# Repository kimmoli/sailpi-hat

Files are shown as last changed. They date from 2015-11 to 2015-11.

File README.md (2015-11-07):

sailpi-hat
==========

Sensors:

  - ADXL345 acceleration sensor (i2c 0x53)
  - BMP180 pressure sensor (i2c 0x77)
  - MCP9800 temperature sensor (i2c 0x4d)
  - MCP3021 AD converter (i2c 0x48)

Connectors:

X2
--

  - 1 +5V output
  - 2 +5V output
  - 3 GND
  - 4 GND
  - 5 shutdown input (connect to GND to shutdown)
  - 6 +12V input
  - 7 +12V input
  - 8 GND
  
X3
--

  - 1 optional analog input (R4B)
  - 2 GND
  - 3 Not connected
  - 4 SCL1
  - 5 SDA1
  - 6 Not connected
  - 7 +3.3V output
  - 8 GND

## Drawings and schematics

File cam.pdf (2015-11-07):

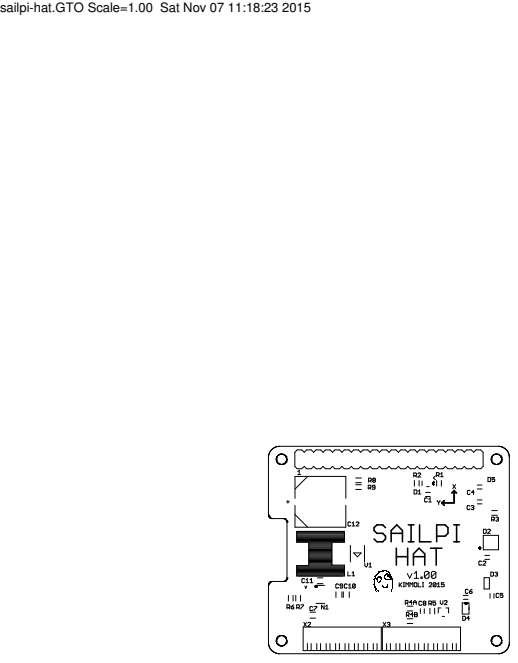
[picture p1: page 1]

sailpi-hat.GTO Scale=1.00 Sat Nov 07 11:18:23 2015

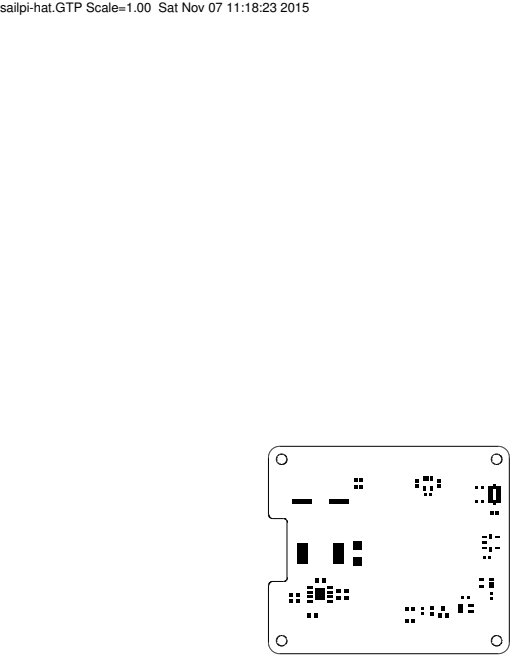
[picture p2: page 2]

sailpi-hat.GTP Scale=1.00 Sat Nov 07 11:18:23 2015

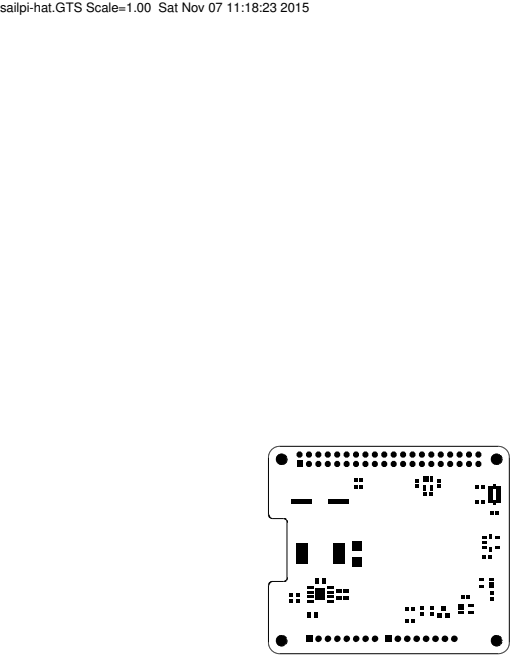
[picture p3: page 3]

sailpi-hat.GTS Scale=1.00 Sat Nov 07 11:18:23 2015

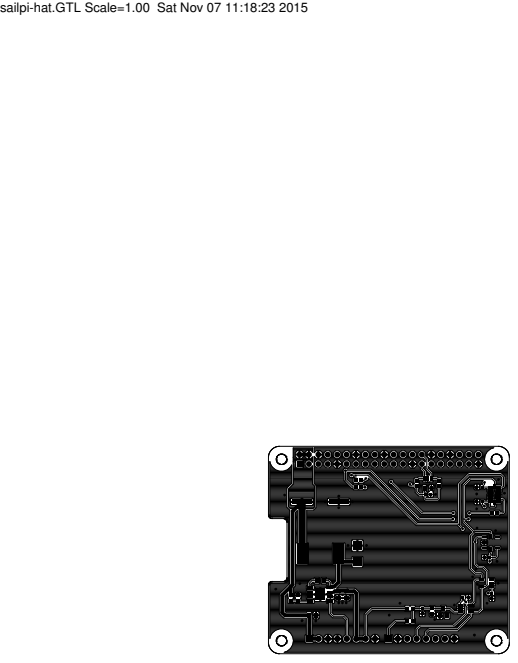
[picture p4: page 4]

sailpi-hat.GTL Scale=1.00 Sat Nov 07 11:18:23 2015

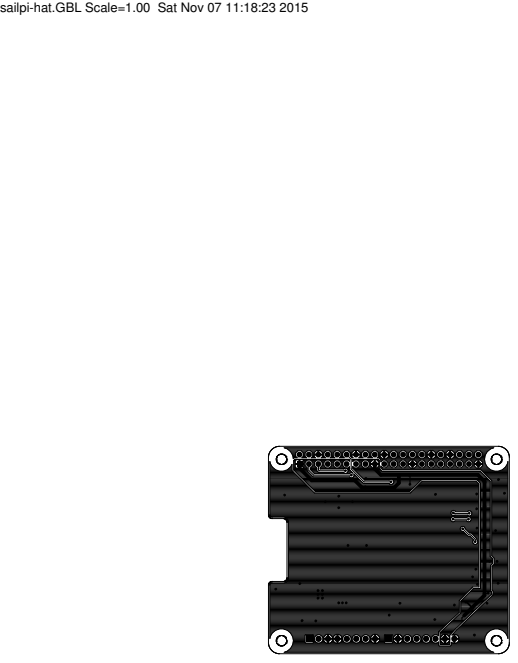
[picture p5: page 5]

sailpi-hat.GBL Scale=1.00 Sat Nov 07 11:18:23 2015

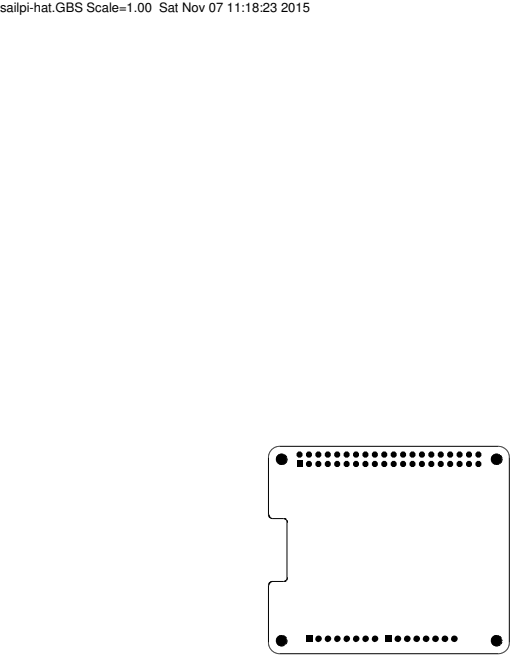
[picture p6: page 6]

sailpi-hat.GBS Scale=1.00 Sat Nov 07 11:18:23 2015

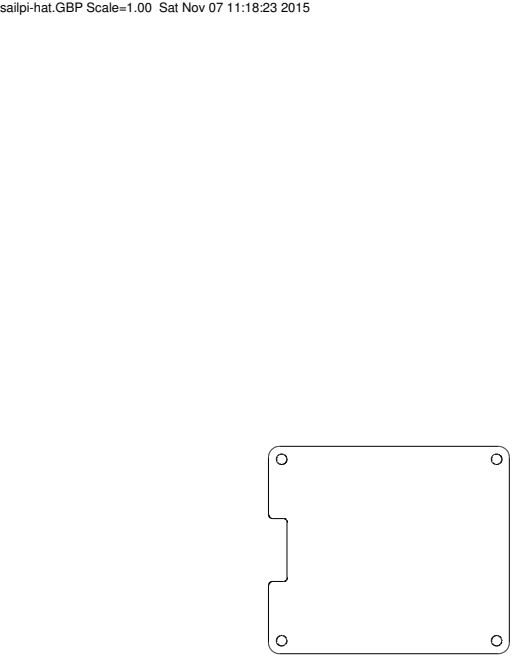
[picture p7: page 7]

sailpi-hat.GBP Scale=1.00 Sat Nov 07 11:18:23 2015

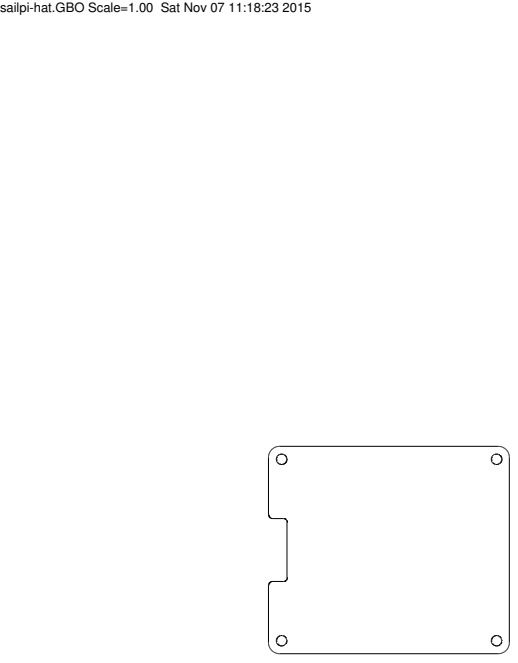
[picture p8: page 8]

sailpi-hat.GBO Scale=1.00 Sat Nov 07 11:18:23 2015

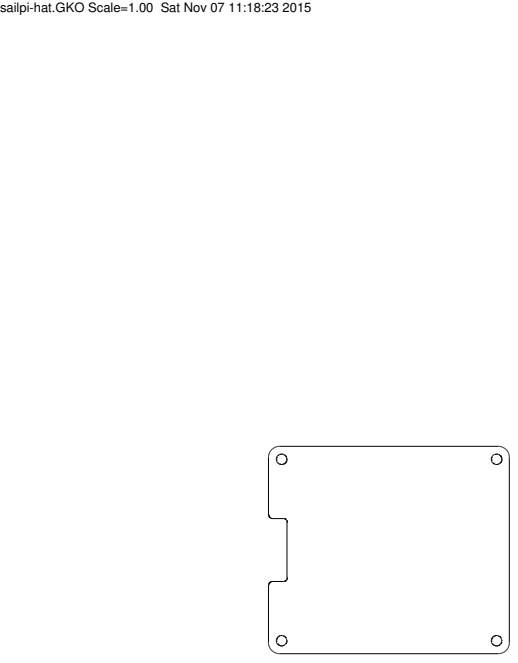
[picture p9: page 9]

sailpi-hat.GKO Scale=1.00 Sat Nov 07 11:18:23 2015

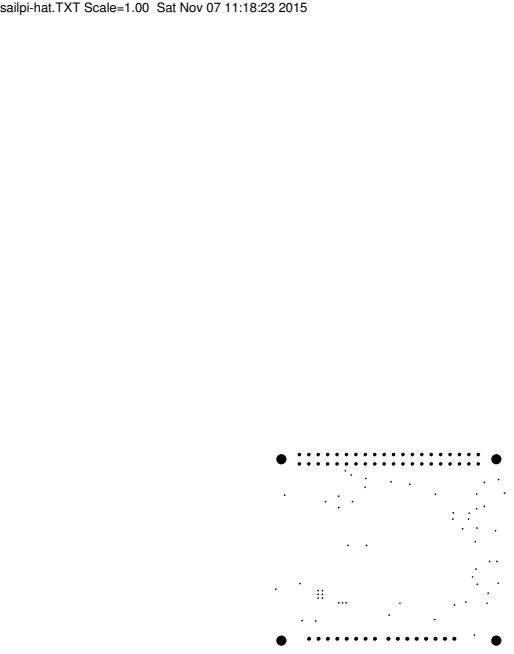
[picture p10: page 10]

sailpi-hat.TXT Scale=1.00 Sat Nov 07 11:18:23 2015

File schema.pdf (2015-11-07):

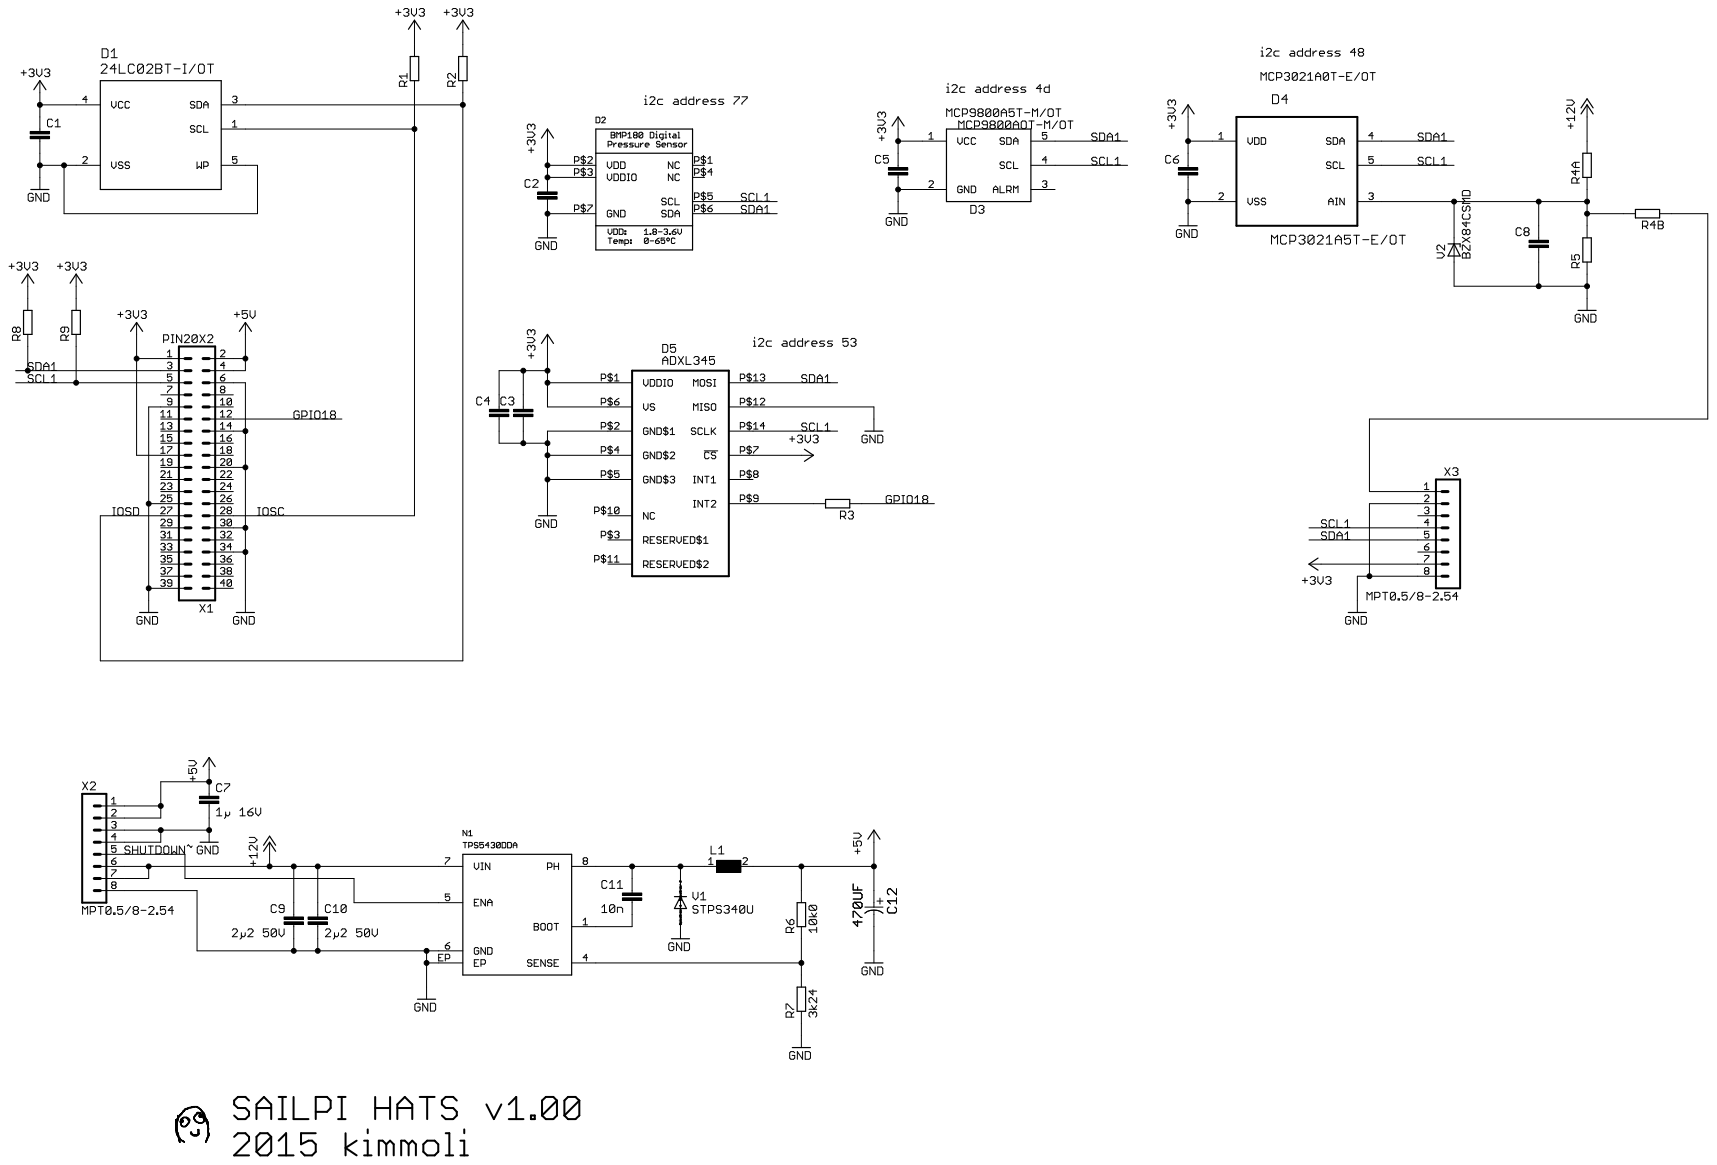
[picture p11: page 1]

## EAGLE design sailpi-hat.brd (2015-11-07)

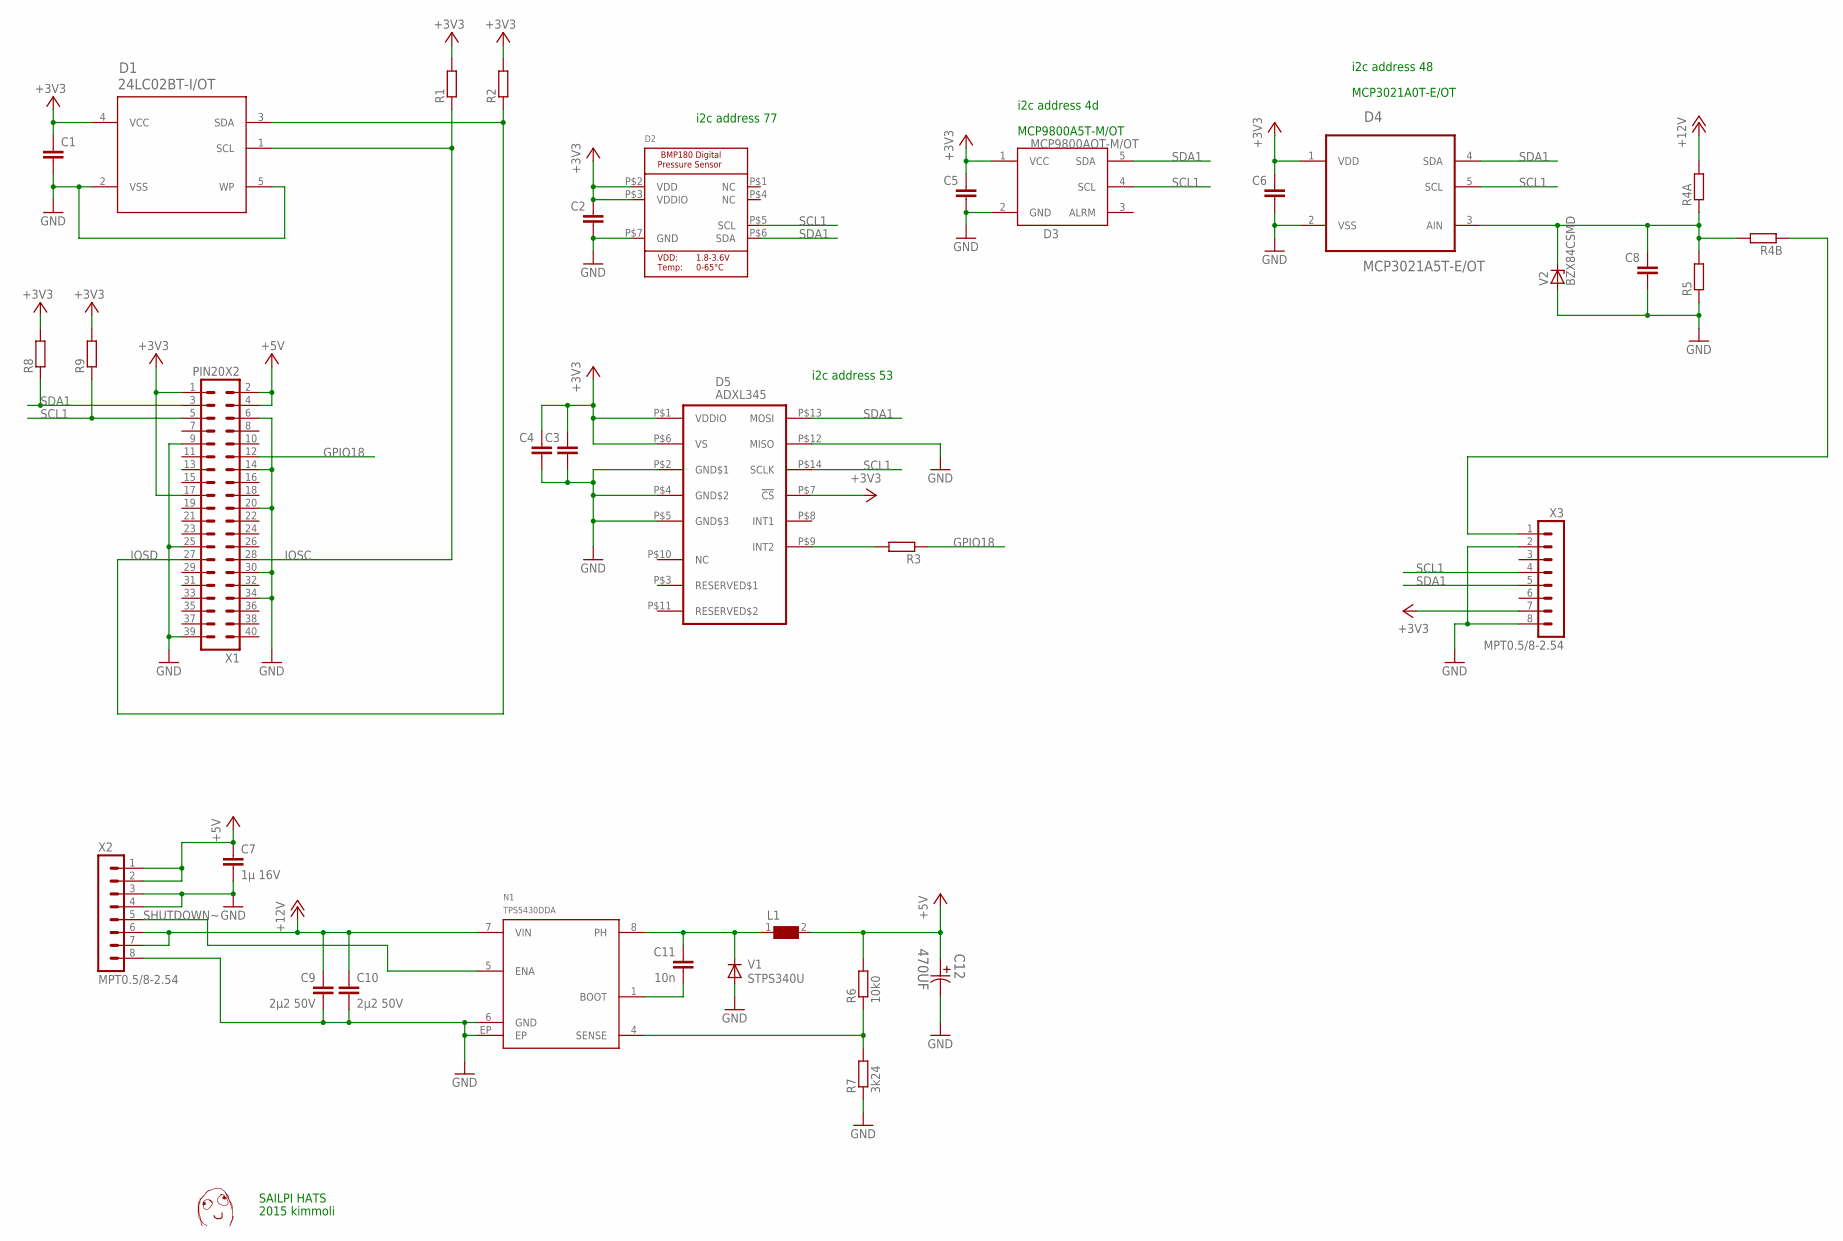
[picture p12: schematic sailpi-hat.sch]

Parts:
C1, C2, C3, C4, C5, C6, C8: CAP0603; C0603
C7: 1µ 16V; C0805
C9, C10: 2µ2 50V; C0805
C11: 10n; C0805
C12: 470UF; CAPAE1350X1400N
D1: 24LC02BT-I/OT; SOT95P280X145-5N
D2: BMP180EXT; BMP180_EXTENDED
D3: MCP9800AOT-M/OT; SOT23-5
D4: MCP3021A5T-E/OT; SOT95P270X145-5N
D5: ADXL345; LGA14
L1: WE-PD-7447709220_1260/1245/1280/1210; WE-PD_1260/1245/1280/1210
N1: TPS5430DDA; SOIC8-N-EP
R1, R2, R3, R4A, R4B, R5, R8, R9: RES0603; R0603
R6: 10k0; R0603
R7: 3k24; R0603
U$2: DAFUG
V1: STPS340U; SMB
V2: BZX84CSMD; TO236
X1: PIN20X2; PIN_20X2
X2, X3: MPT0.5/8-2.54

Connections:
+3V3: C1.1, C2.1, C3.1, C4.1, C5.1, C6.1, D1.4 (VCC), D2.P$2 (VDD), D2.P$3 (VDDIO), D3.1 (VCC), D4.1 (VDD), D5.P$1 (VDDIO), D5.P$6 (VS), D5.P$7 (!CS), R1.2, R2.2, R8.2, R9.2, X1.1, X1.17, X3.7
+5V: C7.1, C12.1, L1.2, R6.2, X1.2, X1.4, X2.1, X2.2
+12V: C9.1, C10.1, N1.7 (VIN), R4A.2, X2.6, X2.7
GND: C1.2, C2.2, C3.2, C4.2, C5.2, C6.2, C7.2, C8.2, C9.2, C10.2, C12.2, D1.2 (VSS), D1.5 (WP), D2.P$7 (GND), D3.2 (GND), D4.2 (VSS), D5.P$2 (GND$1), D5.P$4 (GND$2), D5.P$5 (GND$3), D5.P$12 (MISO), N1.6 (GND), N1.EP, R5.1, R7.1, V1.A, V2.A, X1.6, X1.9, X1.14, X1.20, X1.25, X1.30, X1.34, X1.39, X2.3, X2.4, X2.8, X3.2, X3.8
GPIO18: R3.1, X1.12
IOSC: D1.1 (SCL), R1.1, X1.28
IOSD: D1.3 (SDA), R2.1, X1.27
unnamed: D5.P$9 (INT2), R3.2
unnamed: R4B.1, X3.1
unnamed: C8.1, D4.3 (AIN), R4A.1, R4B.2, R5.2, V2.C
unnamed: C11.1, L1.1, N1.8 (PH), V1.C
unnamed: C11.2, N1.1 (BOOT)
unnamed: N1.4 (SENSE), R6.1, R7.2
SCL1: D2.P$5 (SCL), D3.4 (SCL), D4.5 (SCL), D5.P$14 (SCLK), R9.1, X1.5, X3.4
SDA1: D2.P$6 (SDA), D3.5 (SDA), D4.4 (SDA), D5.P$13 (MOSI), R8.1, X1.3, X3.5
SHUTDOWN~: N1.5 (ENA), X2.5

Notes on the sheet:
i2c address 53
i2c address 77
MCP9800A5T-M/OT
i2c address 4d
MCP3021A0T-E/OT
i2c address 48
SAILPI HATS
2015 kimmoli

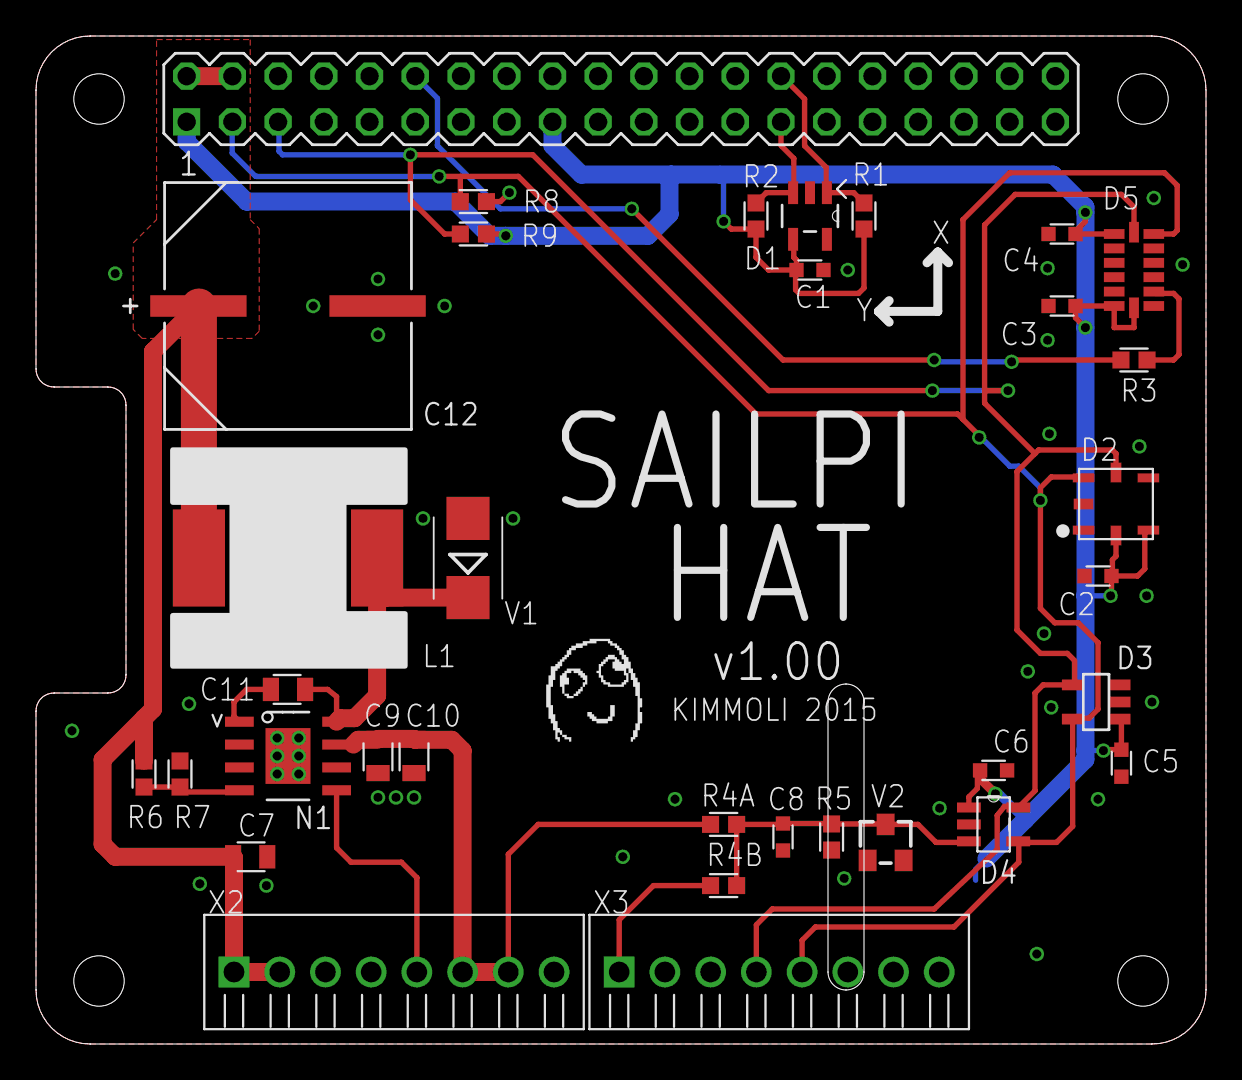
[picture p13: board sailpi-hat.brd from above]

Board: 2 copper layers, 65.0 x 56.0 mm, 35 parts (0 on the bottom side), 16 nets.
